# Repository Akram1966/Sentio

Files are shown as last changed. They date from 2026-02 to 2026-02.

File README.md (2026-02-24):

This is the github repo created for the submission of my smart-home-and-wearables-project-contest-2025 by circuit digest, sponsered by digikey.
You must change the wifi name and password in both sentio.yaml and doorbell.yaml. The way to get them both working fully would be to create a folder on your pc, run _pip install esphome_ (install python first) and this will create the esphome files. Next add the images folder here, along with all the code files. Finally, open terminal in this folder and run _esphome run sentio.yaml_ and _esphome run doorbell.yaml_

Project Concept:
I propose "Sentio," a project that reimagines the smart home assistant as an interactive "digital pet" rather than a lifeless tool. While most smart speakers are static cylinders, Sentio is an emotive, privacy-focused robot that is interactive and reacts to touch. Crucially, it serves as a central "Guardian" for the home: it integrates a custom Smart Video Doorbell for secure local streaming and supports Emergency Pagers for elderly care. This combines the engagement of a companion robot with the utility of a secure, offline home automation hub.

Hardware Architecture:
The brain of the system is the ESP32-S3-BOX-3, selected for its offline AI capabilities and built-in peripherals.

Kinetic Movement: The device will be mounted on a 3D-printed turntable driven by an MG90/SG90 Micro Servo. This allows the "head" to pan left/right to look at the user or shake its head.
Sensors:
Touch: One TTP223 capacitive sensor embedded in the casing and the touch sensitive home button allows the user to "pet" the device.
Motion: Using an external mpu6050 accelerometer, Sentio will detect when it is physically picked up.
Vision & RF: A separate ESP32-CAM module will act as the wireless doorbell, and a 433MHz RF Receiver connected to the Box-3’s GPIO dock will listen for signals from wireless panic buttons (pagers).

Software Approach:
I will build the firmware using ESPHome for seamless integration with Home Assistant.

UI & Graphics: Since standard OLED libraries don't work on the Box-3's color LCD, I will use LVGL (Light and Versatile Graphics Library) to render procedural eye animations. A complex state machine will govern the emotions:
Interactive: "Happy" (wiggles) when petted; "Surprised" if touched while sleeping; "Dizzy" (spirals) if the IMU detects the device is being carried/shaken.
Passive: "Sleeping" automatically at night or after inactivity; "Hungry/Sad" randomly to demand attention;
Video Integration: The doorbell feed will be an on-demand MJPEG stream over UDP, ensuring low latency on the Box-3’s display without external cloud servers.

Development Methodology:
Phase 1 (The Personality): Develop the LVGL eye animations and state machine. Integrate the TTP223 sensor and the external IMU to perfect the "pet" behavior (sleeping, happy, dizzy states).
Phase 2 (The Mechanics & Safety): Design the 3D-printed servo base and integrate the 433MHz RF receiver for the elderly pagers.
Phase 3 (The Vision): Build and code the external ESP32-CAM doorbell node and optimize the Wi-Fi video streaming to the main unit.

Why This Board?
The ESP32-S3-BOX-3 is the perfect candidate because it consolidates a display, microphones, and a speaker into one package. The expansion dock provides the necessary I/O for the servo and RF receiver, making it possible to build a complex robot without a mess of external wires.

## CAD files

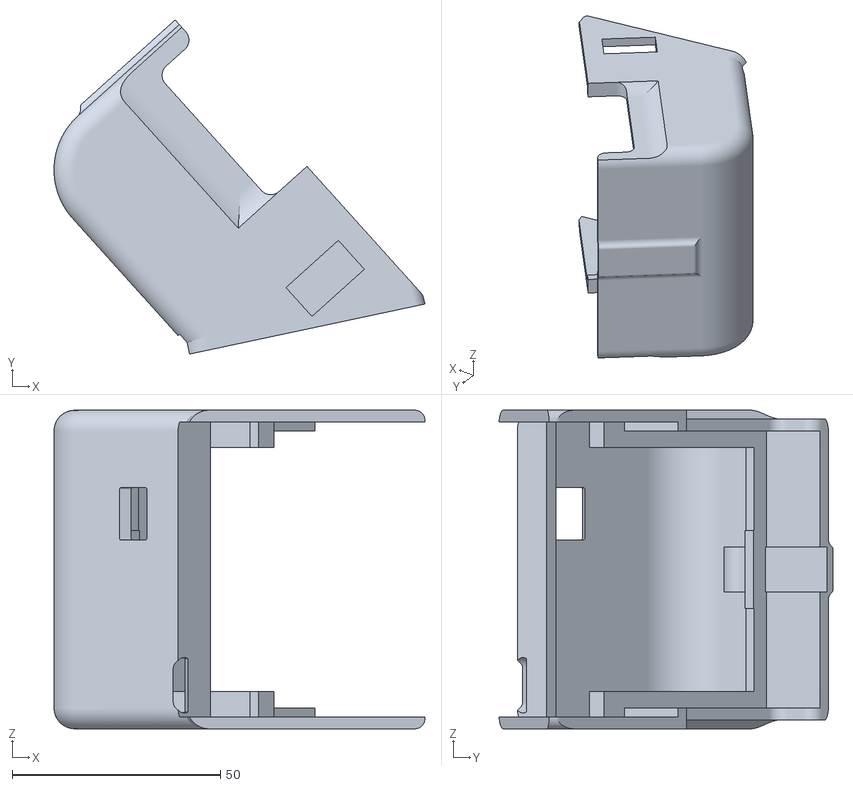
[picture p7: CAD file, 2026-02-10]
stl files/top.stl
89.1 x 80.2 x 76.5

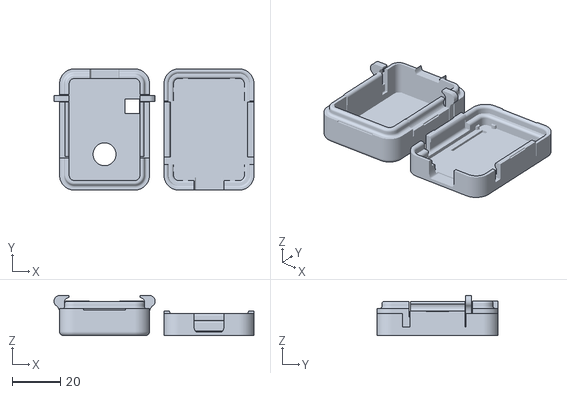
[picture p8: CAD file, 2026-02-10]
stl files/esp32cam_case.stl
83.1 x 50.4 x 16.7

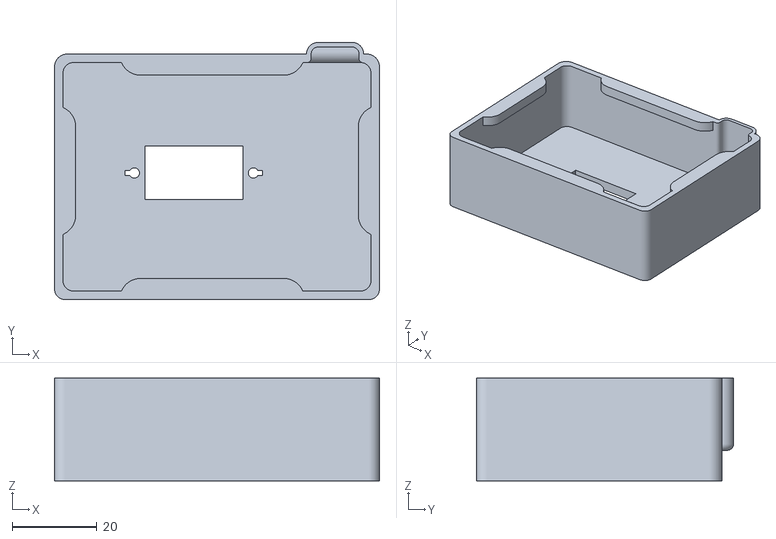
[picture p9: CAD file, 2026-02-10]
stl files/middle.stl
76.5 x 60.5 x 24.2

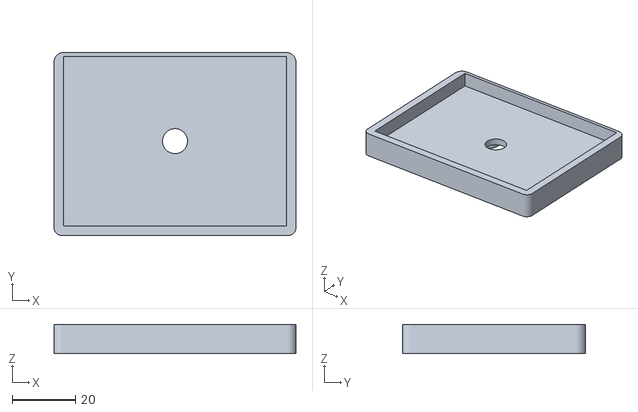
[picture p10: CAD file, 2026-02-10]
stl files/bottom.stl
76.5 x 57.8 x 9.30

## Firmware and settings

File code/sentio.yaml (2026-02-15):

substitutions:
  name: sentio-pet
  friendly_name: Sentio

esphome:
  name: ${name}
  friendly_name: ${friendly_name}
  min_version: 2024.6.0
  name_add_mac_suffix: true
  project:
    name: "Sentio.PetBot"
    version: "135.0" # Fix Suicide Bug
  
  platformio_options:
    board_build.partitions: partitions.csv
  
  # --- INCLUDE DRIVER ---
  includes:
    - web_image.h
  
  libraries:
    - "Bodmer/TJpg_Decoder"

  on_boot:
    priority: 600
    then:
      - light.turn_on: backlight
      - switch.turn_on: speaker_amp
      - servo.write: { id: head_servo, level: 0.0 }
      
      - delay: 1s
      - media_player.volume_set: { id: sentio_speaker, volume: 1.0 }
      
      # --- START IN PET MODE ---
      - lambda: 'id(is_doorbell_mode) = false;'
      - lambda: 'id(is_paged) = false;'
      - script.execute: random_blink
      - script.execute: idle_watchdog
      - script.execute: engine_tick
      
      # Startup Sound
      - media_player.play_media:
          id: sentio_speaker
          media_url: "https://raw.githubusercontent.com/Akram1966/sentio-sounds/main/happy1.wav"

esp32:
  board: esp32s3box
  flash_size: 16MB
  framework:
    type: arduino

psram:
  mode: octal
  speed: 80MHz

logger:
  hardware_uart: USB_SERIAL_JTAG
  level: ERROR

api:
  services:
    - service: start_doorbell
      then:
        - script.execute: enter_doorbell_mode

ota:
  - platform: esphome

wifi:
  id: wifi_component
  ssid: "AngryBird"
  password: "123454321"
  ap:
    ssid: "Sentio-Fallback"

# ---------------------------------------------------------
# 🌐 WEB SERVER
# ---------------------------------------------------------
web_server:
  port: 80

# ---------------------------------------------------------
# 🖼️ IMAGE ASSETS
# ---------------------------------------------------------
image:
  - file: "images/eyes_neutral.png"
    id: img_neutral
    resize: 320x240
    type: RGB565
  - file: "images/eyes_blink.png"
    id: img_blink
    resize: 320x240
    type: RGB565
  - file: "images/eyes_happy.png"
    id: img_happy
    resize: 320x240
    type: RGB565
  - file: "images/eyes_sad.png"
    id: img_sad
    resize: 320x240
    type: RGB565
  - file: "images/eyes_curious.png"
    id: img_curious
    resize: 320x240
    type: RGB565
  - file: "images/eyes_angry.png"
    id: img_angry
    resize: 320x240
    type: RGB565
  - file: "images/eyes_sleepy.png"
    id: img_sleepy
    resize: 320x240
    type: RGB565
  - file: "images/eyes_sleep_z.png"
    id: img_sleep_z
    resize: 320x240
    type: RGB565
  - file: "images/eyes_sleep_zz.png"
    id: img_sleep_zz
    resize: 320x240
    type: RGB565
  - file: "images/eyes_sleep_zzz.png"
    id: img_sleep_zzz
    resize: 320x240
    type: RGB565
  - file: "images/eyes_dizzy.png"
    id: img_dizzy
    resize: 320x240
    type: RGB565
  - file: "images/eyes_shy.png"
    id: img_shy
    resize: 320x240
    type: RGB565
  - file: "images/touch_left.png"
    id: img_touch_left
    resize: 320x240
    type: RGB565
  - file: "images/touch_right.png"
    id: img_touch_right
    resize: 320x240
    type: RGB565

font:
  - file: "VT323-Regular.ttf"
    id: debug_font
    size: 30
  - file: "VT323-Regular.ttf"
    id: alert_font
    size: 60

globals:
  - id: current_state
    type: int
    initial_value: '0'
  - id: last_drawn_state
    type: int
    initial_value: '-1'
  
  # --- LOGIC FLAGS ---
  - id: is_doorbell_mode
    type: bool
    initial_value: 'false'
  - id: is_paged
    type: bool
    initial_value: 'false'
    
  - id: ignore_next_release
    type: bool
    initial_value: 'false'

  - id: is_sleeping
    type: bool
    initial_value: 'false'
  - id: is_servo_moving
    type: bool
    initial_value: 'false'
  - id: fps
    type: int
    initial_value: '0'
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
